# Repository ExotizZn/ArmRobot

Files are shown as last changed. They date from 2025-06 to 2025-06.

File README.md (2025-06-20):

# ArmRobot - Le T.I.G.R.E
Ce projet consiste en la conception, la programmation et le contrôle d’un bras robotisé à l’aide d’une carte Arduino. Le bras peut être utilisé pour des tâches simples comme la rotation ou le positionnement d’objets légers.

Animation de la télécommande

## Matériel nécessaire

- 2 × Carte Arduino UNO R3
- 3 × Servomoteurs MG995
- 3 x Servomoteurs MG90S
- 1 × Alimentation externe (5V / 3A recommandée)
- 6 potentiomètres
- 1 HC06 & 1 HC05 ou 2 HC05
- Vis M3
- Fils de connexion
- Structure du bras

## Prérequis
- SDL2, SDL2_ttf, SDL2_gfx & zenity
```bash
sudo apt update
sudo apt install -y build-essential libsdl2-dev libsdl2-ttf-dev libsdl2-gfx-dev zenity
```

## Installation
### Compiler l'interface de contrôle
```bash
git clone https://github.com/ExotizZn/ArmRobot.git
cd ArmRobot
make
```
### Compiler et téléverser le firmware du robot sur l'arduino
1. Ouvrir le fichier "robotarm_firmware/robotarm_firmware.ino" dans Arduino IDE
2. Compiler et téléverser sur la carte Arduino.

### Compiler et téléverser le firmware de la télécommande sur l'arduino 
1. Ouvrir le fichier "remote_firmware/remote_firmware.ino" dans Arduino IDE
2. Compiler et téléverser sur la carte Arduino.

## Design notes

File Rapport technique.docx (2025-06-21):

Rapport technique – Développement et contrôle d’un bras robotique

1. Objectifs

- Étudier et améliorer un modèle 3D de bras robotique.
- Programmer le contrôle fluide des servomoteurs via Arduino.
- Concevoir une application PC en langage C pour piloter le bras (interface série/Bluetooth).
- Développer un boîtier de contrôle physique Bluetooth avec boutons et potentiomètres.
- Mettre en place un suivi de projet clair et documenter toutes les étapes.

2. Analyse et conception mécanique

Étude des pièces à imprimer

- Fichiers STL des pièces par plateau d’impression.
- Points faibles détectés : jeu mécanique, fixation instable des servos.

Matériaux utilisés

- PLA choisi pour sa facilité d'impression et PETG pour sa solidité.
- Impression avec une épaisseur de couche de 0,2 mm et 15 % d’infill.

3. Composants

Carte Arduino UNO R3

- Microcontrôleur utilisé pour piloter les servos et gérer les communications.
- Fiche technique : Arduino UNO R3 (https://docs.arduino.cc/resources/datasheets/A000066-datasheet.pdf)

Servomoteurs

- MG995 : couple élevé, utilisé pour la base et les articulations principales.
  - Datasheet MG995 (https://www.electronicoscaldas.com/datasheet/MG995_Tower-Pro.pdf)
- MG90S : plus petit et rapide, utilisé pour les pinces.
  - Datasheet MG90S (https://www.electronicoscaldas.com/datasheet/MG90S_Tower-Pro.pdf)

Modules Bluetooth

- HC-05 : utilisé côté Arduino du boîtier en mode maître.
  - Datasheet HC-05 (https://components101.com/sites/default/files/component_datasheet/HC-05%20Datasheet.pdf)
- HC-06 : utilisé pour l’Arduino du robot (mode esclave uniquement).
  - Datasheet HC-06 (https://www.alldatasheet.fr/datasheet-pdf/view/1179032/ETC1/HC-06.html)

4. Câblage et Schéma Électrique

Connexions de base

- Servomoteurs connectés aux broches PWM de l’Arduino.
- HC-05 connecté via RX/TX (avec diviseur de tension pour RX).

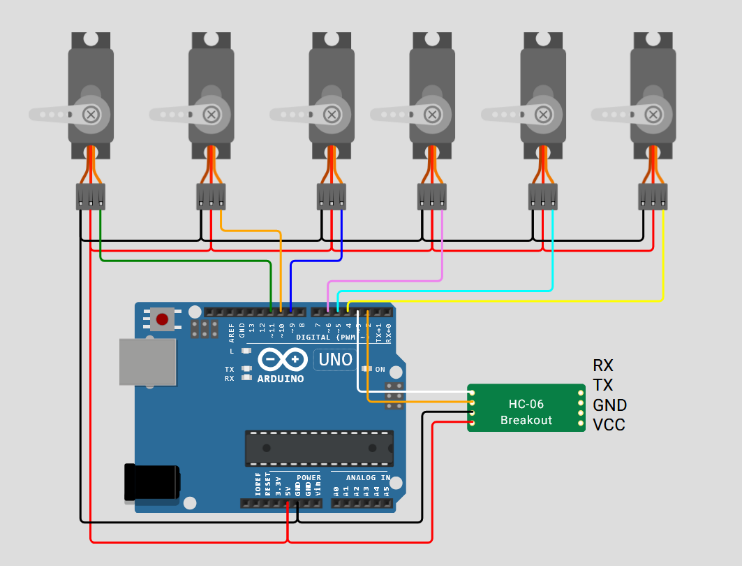
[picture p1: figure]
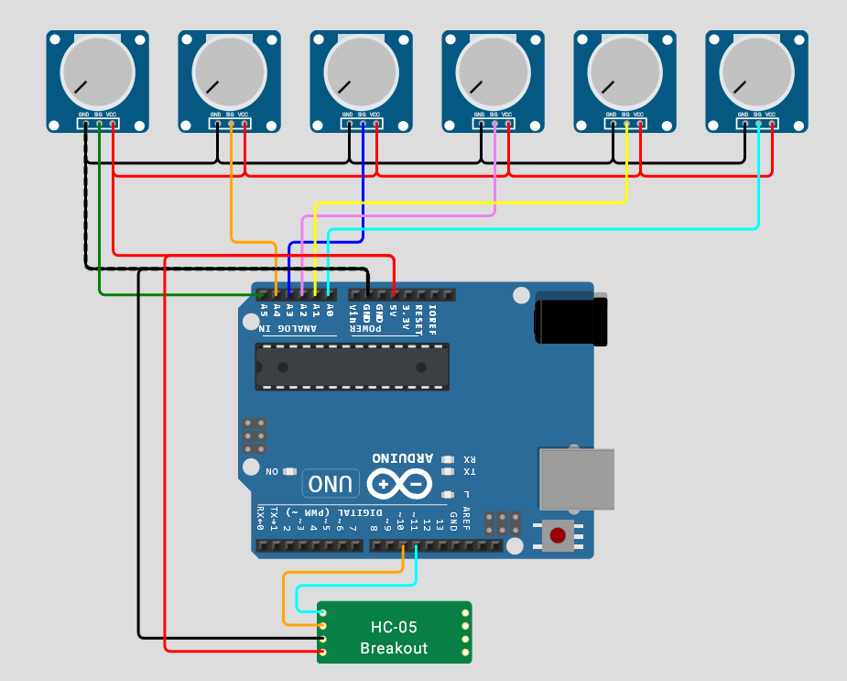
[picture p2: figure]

Programmation Arduino

- Utilisation de la bibliothèque Servo.h.
- Traitement des commandes Bluetooth en temps réel.
- Communication série interprétée sous forme de commandes : S N°SERVO ANGLE (0 à 180°)

5. Application PC en Langage C

- Interface SLD2 en C.
- Communication via port série (USB ou Bluetooth).
- Fonctionnalités :
  - Contrôle manuel avec les curseurs
  - Possibilité d’importer/exporter/sauvegarder et réinitialiser les positions.

6. Boîtier de Contrôle Bluetooth

- Boîtier physique imprimé avec emplacements pour :
  - 6 potentiomètres logarithmiques
  - 1 potentiomètre linéaire
  - 4 boutons
- Communication Bluetooth

7. Tests Réalisés

- Tests mécaniques : résistance des supports, amplitude max.
- Tests de communication : stabilité Bluetooth, portée, latence.
- Tests logiciels : exécution de commandes simultanées.

8. Problèmes rencontrés

- Interférences RX/TX entre Arduino et Bluetooth → solution : delay + diviseur de tension.
- Surchauffe des moteurs → ajout de pauses dans les séquences.
- Limite de courant USB → alimentation externe 5V 2A pour les moteurs

9. Innovations à intégrer

- Base de reconnaissance vocale via micro.
- Ajout d’une caméra

10. Suivi de projet

Utilisation de GitHub

11. Conclusion

Ce projet nous a permis de maîtriser l’ensemble de la chaîne de développement mécatronique : modélisation 3D, programmation embarquée, développement logiciel, communication Bluetooth, gestion d’un projet technique et rédaction d’un rapport structuré.

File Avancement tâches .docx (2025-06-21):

Avancement des tâches :

- 22/05/2025

- Installation Arduino IDE 2.3.6

- Mise en place du Teams

- Test des composants
- Test de la synchronisation des moteurs
- Test des potentiomètres

- Test du Bluetooth

- 23/05/2025

- Installation Fusion 360

- Installation Putty

- 26/05/2025

- Formation imprimante au 3D Fablab

- 27/05/2025

- Installation Prusa Slicer

- Impression des premières pièces : Plateau_1.3mf (https://yncrea-my.sharepoint.com/:u:/g/personal/naman_nguyen_isen_yncrea_fr/EQgqpLK84VJBgo6dkoz6hyMBb4kr6SYq2qxdD1rgIiEaYg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)

- Création GitHub
- Ponçage/Lissage des pièces

- 03/06/2025

- Impression de la suite des pièces : Plateau_2.3mf (https://yncrea-my.sharepoint.com/:u:/g/personal/naman_nguyen_isen_yncrea_fr/Eby0ZBtwWxFHm7vhLbLZPvwB82JhSTI6W2n37s5vbxn5ZA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) et Plateau_3.3mf (https://yncrea-my.sharepoint.com/:u:/g/personal/naman_nguyen_isen_yncrea_fr/EV3YXmqTTMNIu8ltJ17ycAoBfFLF50W6WK41nfajkEYnqA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)

- Ponçage/Lissage des pièces

- Récupération des vis

- Assemblage du bras robot avec les moteurs, les pièces imprimées en 3D, le cable management

- 04/06/2025

- Soudure des câbles

- Connexion des câbles à l’Arduino pour permettre de faire bouger les articulations du robot grâce à l’ordinateur via l’application Arduino IDE

- 05/06/2025

- Design du boîtier de commande du robot

- Calibrage des moteurs, résolution du blocage du moteur de la pince du robot
- Module Bluetooth HC-06 sur Arduino du robot pour télécommander depuis l’ordinateur

- Commande du module HC-05 pour la télécommande

- Branchement propre des fils à l’Arduino et installation dans le socle

- Moteur de la pince cassé

- Autre moteur au Fablab
- Bras robotique relativement commandable en Bluetooth via manette PS4 branchée à l’ordinateur

- 06/06/2025

- Modélisation sur Fusion 360 du boîter télécommande

- Début interface utilisateur pour commander le bras robot

- 07/06/2025

- Interface utilisateur moderne pour le bras robot en SDL2
- Bump des toast de confirmation + fade-out
- Arrière-plan avec étoiles qui défilent de haut en bas assez vite

- Boutons :
*sauvegarder les positions
*exporter les positions
*importer les positions

*jouer une séquence de mouvements (positions)
*réinitialiser les positions à 90°
*arrêter les mouvements du bras robot articulé

- 6 articulations pouvant bouger de 180° avec des curseurs

- 10/06/2025

- Makefile
- Début du PowerPoint
- Optimisation du code de l’interface

- 11/06/2025

- Modification de la modélisation de la télécommande
- Suite PowerPoint
- Guide utilisateur
- Avancement projet
- Excel de répartition des tâches
- Impression du boîtier par Naman

- 12/06/2025

- Teste des composants sur le boîtier
- Ajustements sur la modélisation du boîtier télécommandé
- Réimpression du boîtier avec les bonnes mesures
- Suite du PowerPoint

- 14/06/2025

- Boîtier imprimé avec bonnes mesures
- Placement des composants : Arduino, LEDs, potentiomètres…

- Assemblage du boîtier

- 16/06/2025

- Soudure des potentiomètres et points de colle chaude pour stabiliser le tout
- Ajout du module Bluetooth HC-05
- Câblage des composants
- Changement des moteurs défectueux et réapprovisionnement en fils mâle-femelle
- Appairage des modules Bluetooth du robot et de la télécommande via Arduino IDE pour télécommander le robot

- 17/06/2025

- Ajustements sur le code de l’Arduino pour le robot
- PowerPoint mieux mis en forme

- 18/06/2025

- Pont diviseur de tension autour des deux modules Bluetooth pour que les ports RX/TX soient en 3,3 V au lieu de 5 V

- 19/06/2025

- Ajustements des soudures sur le boîtier
- Amélioration du code de l’Arduino

- Amélioration du logiciel pour commander le robot

- 20/06/2025 - Ajustements sur la télécommande - Fin du PowerPoint

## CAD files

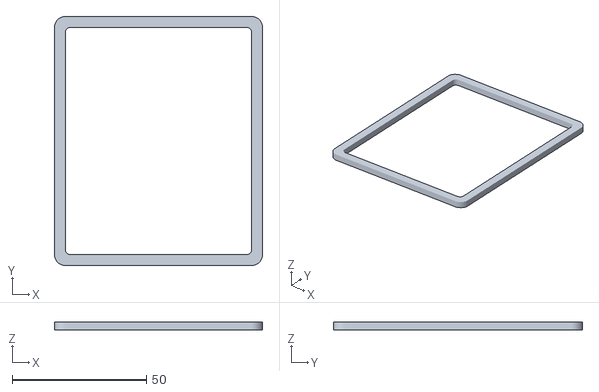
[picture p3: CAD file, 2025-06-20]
remote_stl/mid_part_2.stl
77.3 x 92.6 x 3.00

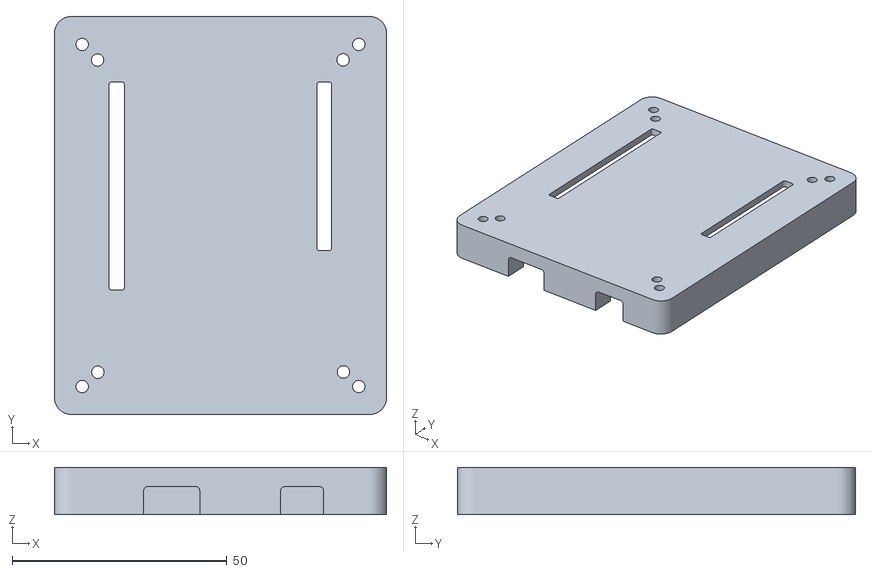
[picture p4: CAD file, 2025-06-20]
remote_stl/mid_part.stl
77.3 x 92.6 x 11.0

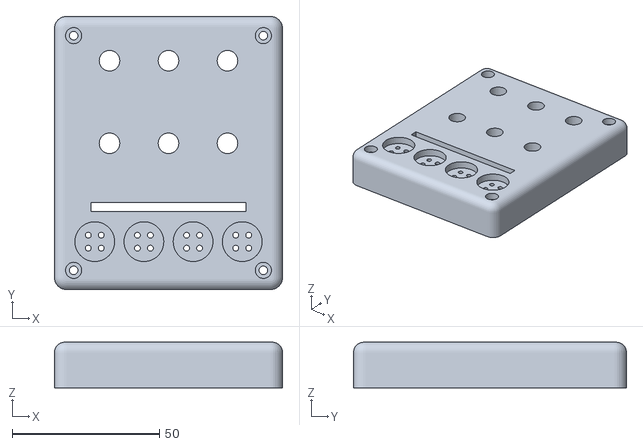
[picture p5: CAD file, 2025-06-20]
remote_stl/top_part.stl
77.3 x 92.6 x 15.5

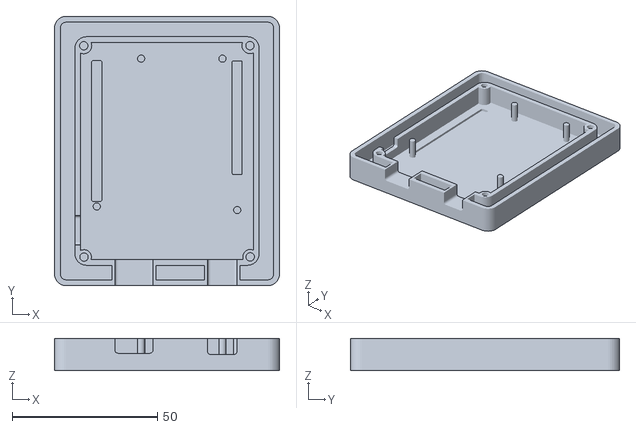
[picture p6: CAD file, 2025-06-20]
remote_stl/base_part.stl
77.3 x 92.6 x 11.0

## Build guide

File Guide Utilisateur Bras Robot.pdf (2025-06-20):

## Guide Utilisateur — Projet Bras Robotique

## Introduction

✨Présentation du projet

Ce projet consiste en la conception d’un bras robotique à 6 axes, contrôlable via :
- Une interface graphique sur ordinateur avec des curseurs (SDL2 en langage C)
- Une télécommande physique imprimée en 3D (boutons, LEDs, potentiomètres)
- Une liaison Bluetooth entre l’Arduino Uno et l’ordinateur ou une télécommande pour l’exécution des commandes

## Instructions de démarrage

🚀Installation et lancement
Compiler le programme sur l’Arduino (fichier .ino) et l’interface SDL2 sur PC avec :

sudo apt update && sudo apt install -y build-essential libsdl2-dev libsdl2-ttf-dev libsdl2-gfx-dev zenity && make && ./ArmRobot
📊Configuration minimale recommandée
- Système d’exploitation : Windows avec WSL ou Linux natif
- Bibliothèques : libSDL2, libSDL2-ttf, libSDL2-gfx
- Arduino UNO

## Fonctionnalités principales

🔹Interface SDL2 (logiciel PC)
- 6 curseurs : pour chaque articulation (M1 à M6)
- Boutons :
- SAUVEGARDER : sauvegarde la position actuelle
- SÉQUENCE : joue une séquence de mouvements
- STOP : arrêter les mouvements du bras
- EXPORTER / IMPORTER : charger/importer des positions
- RÉINITIALISER : retourne en position initiale
🎮Télécommande physique
- 6 potentiomètres rotatifs (M1 à M6)
- 1 potentiomètre linéaire (vitesse)

- 4 boutons (SAUVEGARDER / STOP / SAUVEGARDER / RÉINITIALISER)
- Bande LEDs RGB
🤖Bras robotique
- Servomoteurs commandés via signaux PWM (0-180°)
- Mouvement en temps réel selon les curseurs ou potentiomètres
- Base et squelette stable avec pièces imprimés 3D

## ✅Étapes d’utilisation

Pour utiliser le bras depuis le PC :
1. Allumer l’Arduino
2. Lancer ./ArmRobot
3. Connecter le Bluetooth
4. Bouger les curseurs pour chaque articulation de 180°
5. Appuyer sur les boutons de l’interface logicielle Pour utiliser la télécommande :
1. Tourner les potentiomètres pour ajuster les positions
2. Les LEDs RGB s’allument

## ⚠️Dépannage

Problème | Solution
Aucun mouvement | Vérifier COM Bluetooth + alimentation Arduino
LED qui ne clignote pas | Revoir le câblage HC-05 et la liaison RX/TX
Segmentation fault | SDL2 mal installé, ou police Arial.ttf absente

📅Ressources utiles
- Documentation SDL2 : https://wiki.libsdl.org
- Forum Arduino : https://forum.arduino.cc
- GitHub du projet : https://github.com/ExotizZn/ArmRobot

## 💼Bonnes pratiques

- Préférer l’interface PC pour des déplacements précis
- Ne jamais forcer la pince ou les bras manuellement

## 🌐Conclusion

Vous êtes maintenant capable de contrôler un bras robotique via logiciel ou télécommande physique. Le projet peut être étendu avec de l’IA, une caméra ou des séquences automatisées.

Contact projet :
Evann TARQUINI, Naman NGUYEN, Corentin DE ANGELIS, Léa ARMENGOL

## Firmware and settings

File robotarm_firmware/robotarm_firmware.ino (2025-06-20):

#include <VarSpeedServo.h>
#include <SoftwareSerial.h>

// Configuration Bluetooth HC-06
#define BT_RX 2  // Connecté au TX du HC-06
#define BT_TX 3  // Connecté au RX du HC-06
SoftwareSerial bluetooth(BT_RX, BT_TX);

// Configuration des servos
VarSpeedServo servos[6];
const int servoPins[6] = {4, 5, 6, 9, 10, 11};  // Broches pour Servos 1-6
int currentPositions[6] = {90, 90, 90, 90, 90, 90};
const uint8_t SERVO_SPEED = 50;  // Vitesse des servos (0-255, 50 = modéré)

// Buffers pour la réception
char btBuffer[16];    // Buffer pour Bluetooth
char comBuffer[16];   // Buffer pour port COM
int btIndex = 0;      // Index pour buffer Bluetooth
int comIndex = 0;     // Index pour buffer port COM
const int COMMAND_TIMEOUT = 50;  // Timeout pour compatibilité

void setup() {
  // Initialisation servos
  for (int i = 0; i < 6; i++) {
    servos[i].attach(servoPins[i]);
    servos[i].write(currentPositions[i], SERVO_SPEED, true);  // Mouvement initial à vitesse modérée
  }
  
  // Communication
  Serial.begin(115200);
  bluetooth.begin(38400);  // HC-06 configuré à 115200 bauds
  
  Serial.println("Bras Robot - Prêt à recevoir des commandes via Bluetooth ou port COM");
}

void loop() {
  // Réception Bluetooth
  while (bluetooth.available()) {
    char c = bluetooth.read();
    
    if (c == '\n') {
      btBuffer[btIndex] = '\0';  // Terminer la chaîne
      processCommand(btBuffer, "Bluetooth");
      btIndex = 0;  // Réinitialiser l'index
    } else if (btIndex < sizeof(btBuffer) - 1) {
      btBuffer[btIndex++] = c;
    }
  }

  // Réception port COM
  while (Serial.available()) {
    char c = Serial.read();
    
    if (c == '\n') {
      comBuffer[comIndex] = '\0';  // Terminer la chaîne
      processCommand(comBuffer, "COM");
      comIndex = 0;  // Réinitialiser l'index
    } else if (comIndex < sizeof(comBuffer) - 1) {
      comBuffer[comIndex++] = c;
    }
  }
}

void processCommand(const char *cmd, const char *source) {
  // Ignorer les commandes vides
  if (cmd[0] == '\0') return;
  
  // Afficher la commande reçue avec la source
  Serial.print("Commande reçue via ");
  Serial.print(source);
  Serial.print(": ");
  Serial.println(cmd);

  // Format attendu: "S<num><angle>" (ex: "S1120")
  if (cmd[0] == 'S' && strlen(cmd) >= 3) {
    int servoNum = cmd[1] - '1';  // Convertir '1'-'6' en index 0-5
    int angle = atoi(&cmd[2]);    // Convertir la partie angle
    
    // Validation
    if (servoNum >= 0 && servoNum < 6 && angle >= 0 && angle <= 180) {
      servos[servoNum].write(angle, SERVO_SPEED, true);  // Mouvement à vitesse modérée
      currentPositions[servoNum] = angle;
      
      // Feedback
      Serial.print("Servo ");
      Serial.print(servoNum + 1);
      Serial.print(" → ");
      Serial.print(angle);
      Serial.print("° (via ");
      Serial.print(source);
      Serial.println(")");
      
      // Envoyer le feedback via Bluetooth si la commande vient du port COM
      if (strcmp(source, "COM") == 0) {
        bluetooth.print("Servo ");
        bluetooth.print(servoNum + 1);
        bluetooth.print(" → ");
        bluetooth.print(angle);
        bluetooth.println("°");
      }
    } else {
      Serial.print("Commande invalide: ");
      Serial.println(cmd);
    }
  } else {
    Serial.print("Format incorrect: ");
    Serial.println(cmd);
  }
}

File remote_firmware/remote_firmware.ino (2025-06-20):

#include <SoftwareSerial.h>
#include <FastLED.h>

// ---------- CONFIGURATION LED ----------
#define LED_PIN     6
#define NUM_LEDS    15
#define BRIGHTNESS  100

CRGB leds[NUM_LEDS];

// ---------- CONFIGURATION BLUETOOTH HC-06 ----------
#define BT_RX 10 // Connecté au TX du HC-06
#define BT_TX 11 // Connecté au RX du HC-06
SoftwareSerial bluetooth(BT_RX, BT_TX);

// ---------- CONFIGURATION POTENTIOMÈTRES ----------
const int potPins[6] = {A0, A1, A2, A3, A4, A5};

// ---------- LISSAGE DES VALEURS ----------
const int numReadings = 10;
int readings[6][numReadings];
int readIndex[6] = {0};
int total[6] = {0};
int average[6] = {0};

int currentAngles[6] = {90, 90, 90, 90, 90, 90};
int lastSentAngles[6] = {90, 90, 90, 90, 90, 90};
unsigned long lastSendTime = 0;
const int sendInterval = 100;
const int threshold = 7;

void setup() {
  Serial.begin(9600);
  bluetooth.begin(38400);

  // Pins Bluetooth
  pinMode(BT_RX, INPUT);
  pinMode(BT_TX, OUTPUT);

  // Initialiser LEDs
  FastLED.addLeds<WS2812, LED_PIN, GRB>(leds, NUM_LEDS);
  FastLED.setBrightness(BRIGHTNESS);
  fill_solid(leds, NUM_LEDS, CRGB::White);
  FastLED.show();

  // Initialisation potentiomètres
  for (int i = 0; i < 6; i++) {
    pinMode(potPins[i], INPUT);
    for (int j = 0; j < numReadings; j++) {
      readings[i][j] = 0;
    }
  }

  Serial.println("Contrôleur Bras Robot avec LEDs et Potentiomètres");
}

void loop() {
  for (int i = 0; i < 6; i++) {
    total[i] = total[i] - readings[i][readIndex[i]];
    readings[i][readIndex[i]] = analogRead(potPins[i]);
    total[i] = total[i] + readings[i][readIndex[i]];
    readIndex[i] = (readIndex[i] + 1) % numReadings;
    average[i] = total[i] / numReadings;
    int newAngle = map(average[i], 0, 1023, 180, 0);

    if (abs(newAngle - lastSentAngles[i]) >= threshold && (millis() - lastSendTime > sendInterval)) {
      currentAngles[i] = newAngle;
      sendCommand(i);
      lastSentAngles[i] = currentAngles[i];
      lastSendTime = millis();

      Serial.print("Commande envoyée: S");
      Serial.print(i + 1);
      Serial.println(currentAngles[i]);
    }
  }

  FastLED.show(); // Rafraîchir l’affichage (au cas où tu changes les couleurs plus tard)
  delay(1);
}

void sendCommand(int servoIndex) {
  String command = "S" + String(servoIndex + 1) + String(currentAngles[servoIndex]);
  bluetooth.println(command);
}
